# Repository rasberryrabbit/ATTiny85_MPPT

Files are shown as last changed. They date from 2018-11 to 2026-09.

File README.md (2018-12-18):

# ATTiny85
Solar MPPT circuit.
Fianally working first firmware, but it need more testing.
Button is calibrate op-amp offset voltage at no load. It stored EEPROM.

Coding by Arduino 1.8.7 / ATTinycore.
~Algorithm convert from old MPPT code of mine.~
It implement new simple algorithm that work well with high solar output.
~But it have low power output under low solar output condition(stuck in high voltage).~
It has no PWM noise at high load.(hopely)
It has 8KHz switching frequency.
It works better than old 16f676 or 12f675 version due to no PWM noise.

11 milli-ohm N-ch logic level FET(BUK9511) used for current sensor. 
It can replace by 11 mili-ohm or higher Rds-on(<40 milli) resistance logic level FET.

BUK9511-55A -> BUK9508-55A
Transistor 2N2222A -> BC547 or compatible
Transistor 2N2907A -> BC557 or compatible

L1 100~330uH

LM358N can replace by other pin-compatible regular OP-AMP.

D8-D9 used for 3.6v Reference. Each has about 1.8v voltage drop.

Q1 gate voltage is 3.6v. It's depend on FET specification.

Q1, Q2 can skip heat spreader with low POWER Solar panel. No heat with 10W panel.

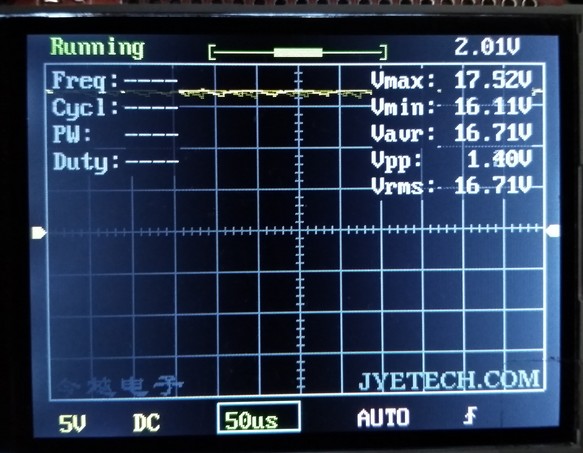
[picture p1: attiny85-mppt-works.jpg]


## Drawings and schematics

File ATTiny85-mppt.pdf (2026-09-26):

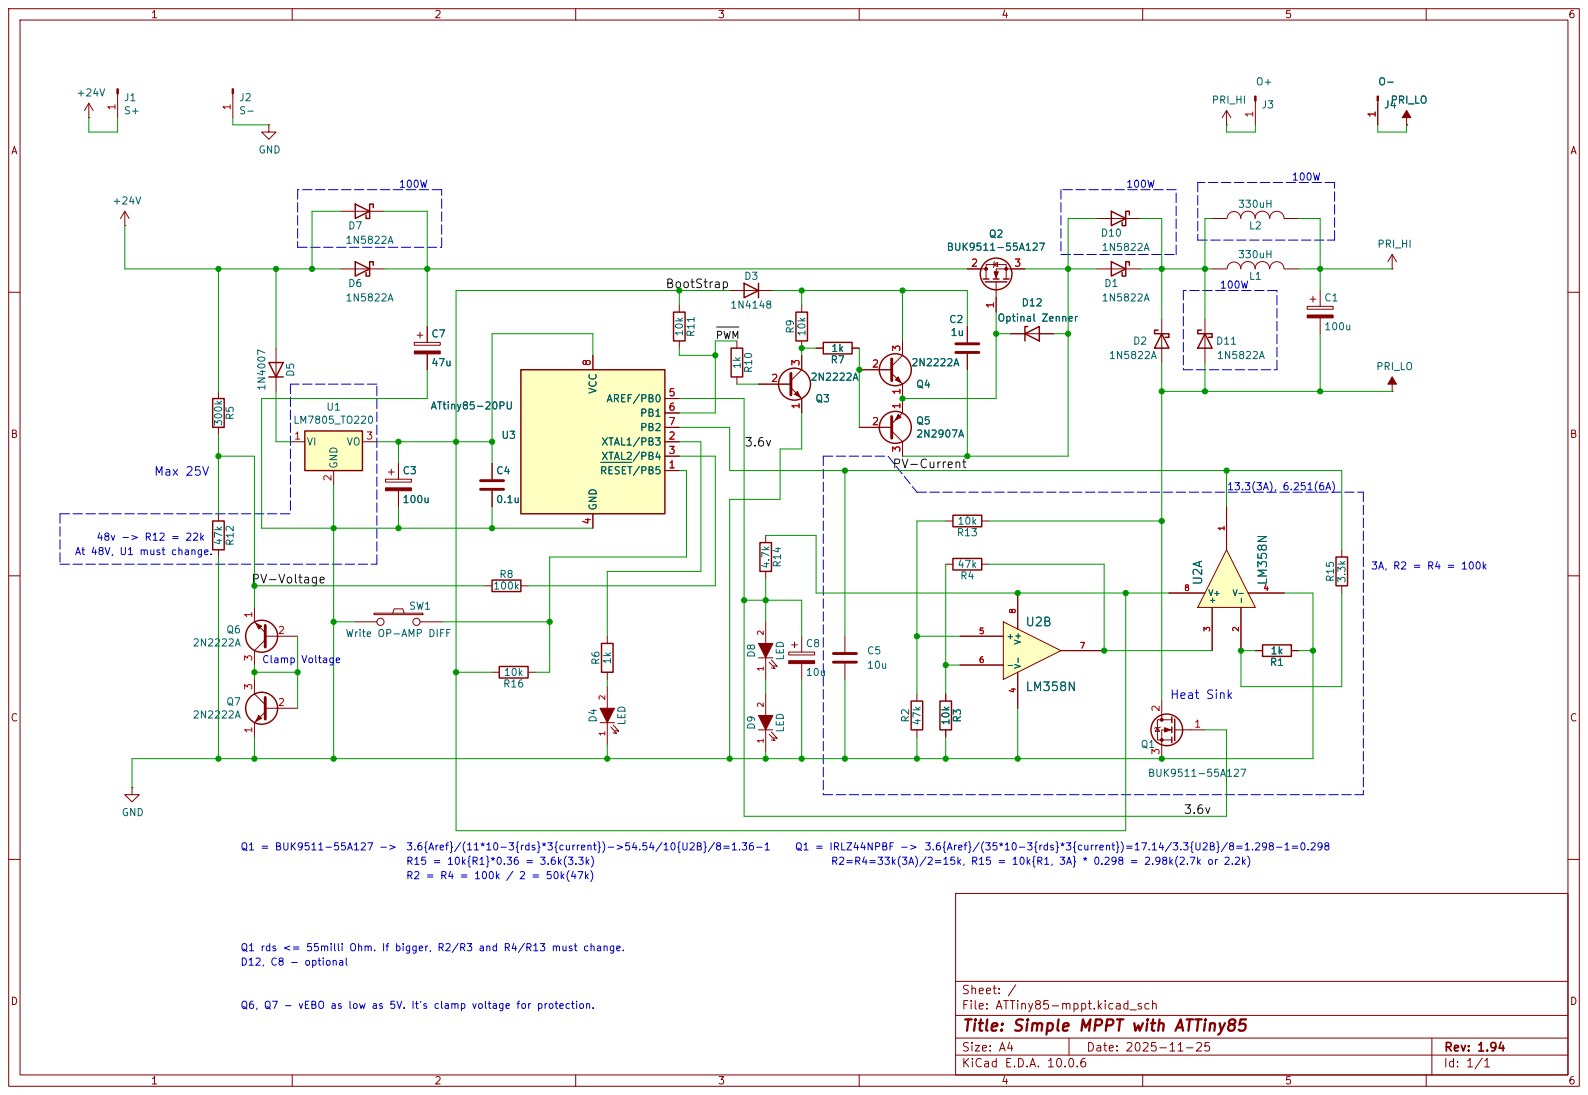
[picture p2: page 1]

Q1 rds <= 55milli Ohm. If bigger, R2/R3 and R4/R13 must change. R2 = R4 = 100k / 2 = 50k(47k)

Sheet: /
File: ATTiny85-mppt.kicad_sch
Title: Simple MPPT with ATTiny85

Q6, Q7 - vEBO as low as 5V. It's clamp voltage for protection.

Size: A4 | Rev: 1.94
KiCad E.D.A. 10.0.6 | Id: 1/1

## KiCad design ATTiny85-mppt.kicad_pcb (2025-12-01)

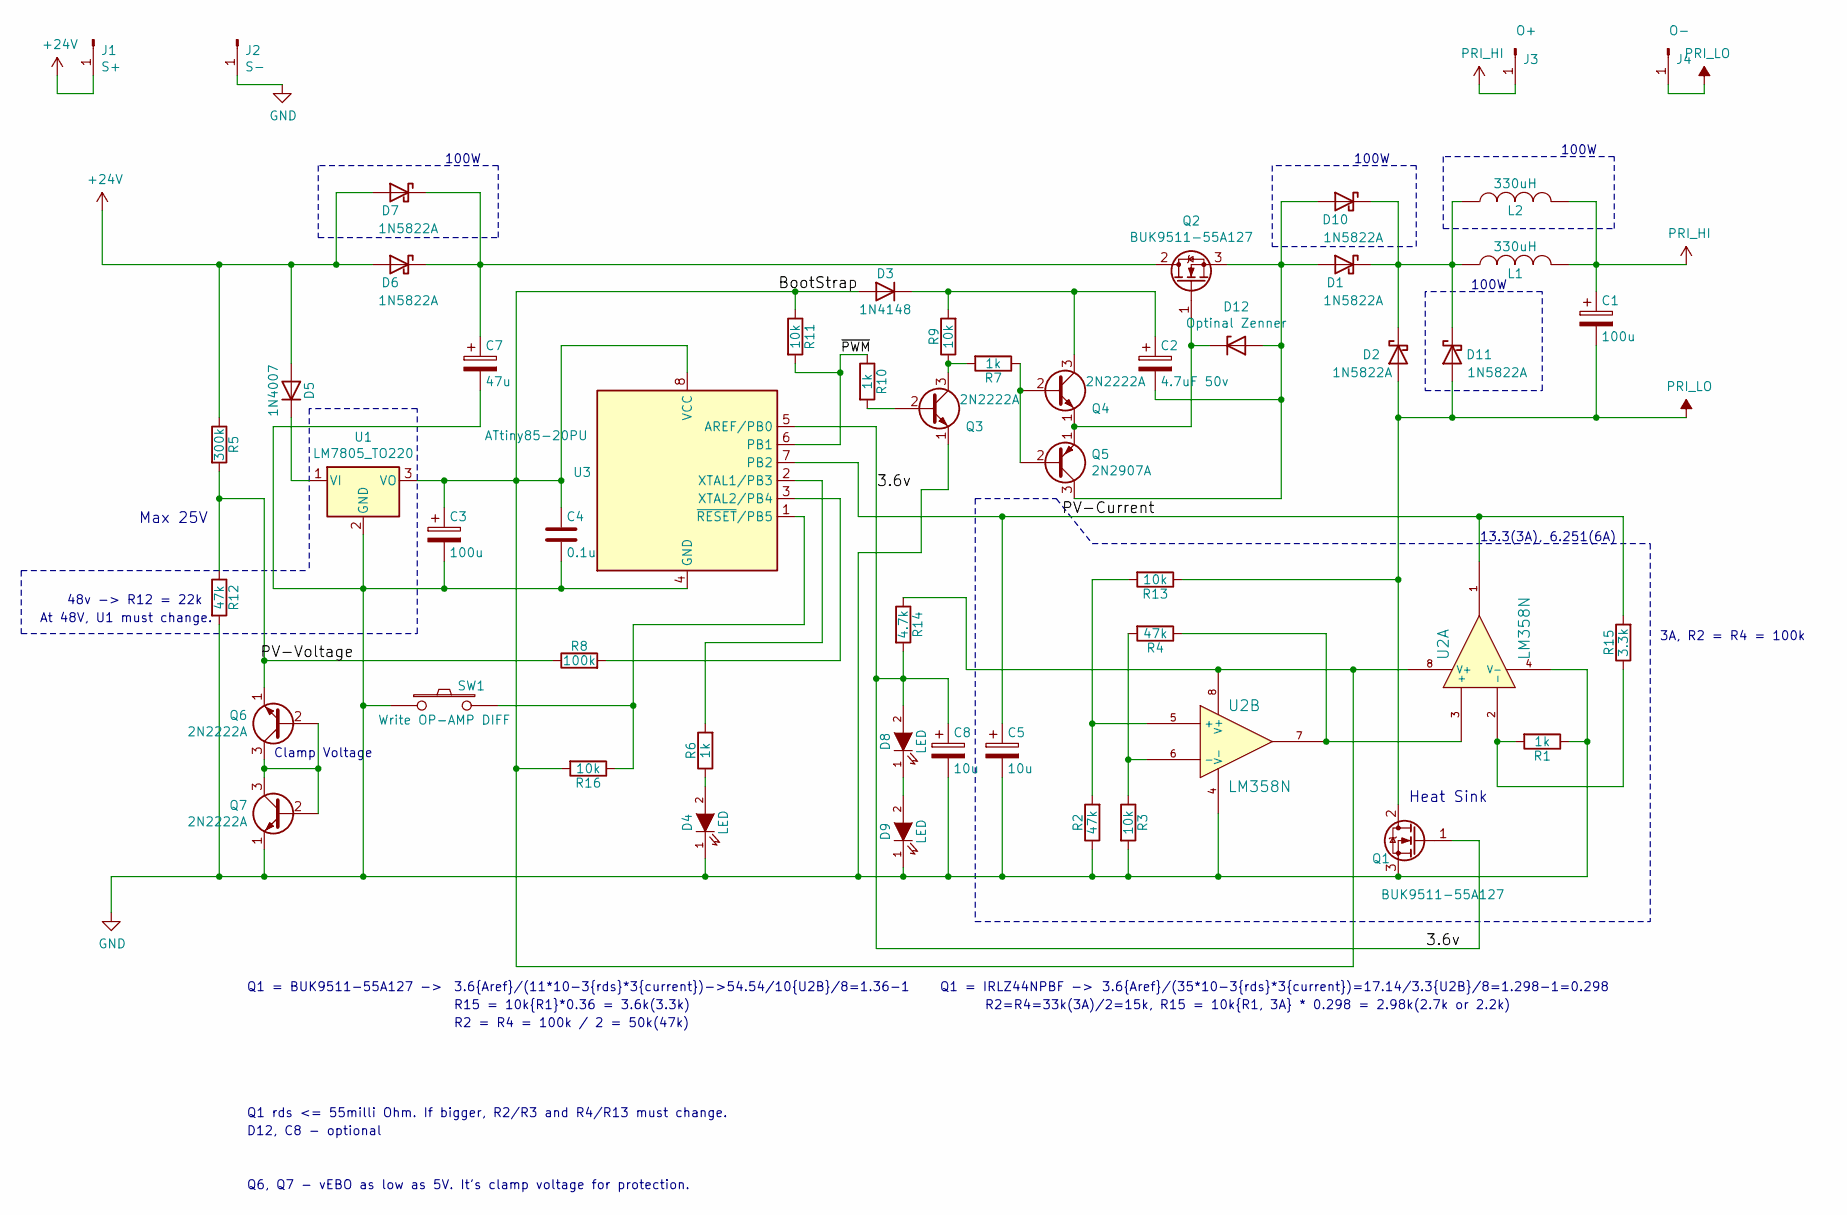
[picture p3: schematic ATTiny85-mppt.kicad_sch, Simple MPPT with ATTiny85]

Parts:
C1, C3: 100u; CP_Radial_D12.5mm_P5.00mm
C2: 4.7uF 50v; CP_Radial_D12.5mm_P5.00mm
C4: 0.1u; C_Disc_D12.5mm_W5.0mm_P7.50mm
C5, C8: 10u; CP_Radial_D12.5mm_P5.00mm
C7: 47u; CP_Radial_D12.5mm_P5.00mm
D1, D2, D6, D7, D10, D11: 1N5822A; D_DO-201AD_P15.24mm_Horizontal
D3: 1N4148; D_DO-41_SOD81_P10.16mm_Horizontal
D4, D8, D9: LED; LED_D4.0mm
D5: 1N4007; D_DO-41_SOD81_P10.16mm_Horizontal
D12: Optinal Zenner; D_DO-41_SOD81_P10.16mm_Horizontal
J1: S+; 1pin
J2: S-; 1pin
J3: O+; 1pin
J4: O-; 1pin
L1, L2: 330uH; L_Toroid_Vertical_L33.0mm_W17.8mm_P12.70mm_Pulse_KM-5
Q1, Q2: BUK9511-55A127; TO-220_Neutral123_Vertical
Q3, Q4, Q6, Q7: 2N2222A; TO-92_Inline_Wide
Q5: 2N2907A; TO-92_Inline_Wide
R1, R6, R7, R10: 1k; R_Axial_DIN0309_L9.0mm_D3.2mm_P12.70mm_Horizontal
R2, R4, R12: 47k; R_Axial_DIN0309_L9.0mm_D3.2mm_P12.70mm_Horizontal
R3, R9, R11, R13, R16: 10k; R_Axial_DIN0309_L9.0mm_D3.2mm_P12.70mm_Horizontal
R5: 300k; R_Axial_DIN0309_L9.0mm_D3.2mm_P12.70mm_Horizontal
R8: 100k; R_Axial_DIN0309_L9.0mm_D3.2mm_P12.70mm_Horizontal
R14: 4.7k; R_Axial_DIN0309_L9.0mm_D3.2mm_P12.70mm_Horizontal
R15: 3.3k; R_Axial_DIN0309_L9.0mm_D3.2mm_P12.70mm_Horizontal
SW1: Write OP-AMP DIFF; SW_PUSH_6mm
U1: LM7805_TO220; TO-220-3_Vertical
U2: LM358N; DIP-8_W7.62mm
U3: ATtiny85-20PU; DIP-8_W7.62mm

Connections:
+24V: D5.2 (A), D6.2 (A), D7.2 (A), J1.1, R5.1; also elsewhere on the board
/3.6v: C8.1, D8.2 (A), Q1.1 (G), R14.2, U3.5 (AREF/PB0)
/BootStrap: C3.1, C4.1, D3.2 (A), R11.1, R14.1, R16.2, U1.3 (VO), U2.8 (V+), U3.8 (VCC)
/PV-Current: C5.1, R15.2, U2.1, U3.7 (PB2)
/PV-Voltage: Q6.1 (E), R5.2, R8.1, R12.1
/~PWM: R10.1, R11.2, U3.6 (PB1)
GND: C3.2, C4.2, C5.2, C7.2, C8.2, D4.1 (K), D9.1 (K), J2.1, Q1.3 (S), Q3.1 (E), Q7.1 (E), R1.1, R2.1, R3.2, R12.2, SW1.1, U1.2 (GND), U2.4 (V-), U3.4 (GND); also elsewhere on the board
unnamed: C2.1, D3.1 (K), Q4.3 (C), R9.2
unnamed: C2.2, D1.2 (A), D10.2 (A), D12.2 (A), Q2.3 (S), Q5.3 (C)
unnamed: C7.1, D6.1 (K), D7.1 (K), Q2.2 (D)
unnamed: D1.1 (K), D2.1 (K), D10.1 (K), D11.1 (K), L1.1, L2.1
unnamed: D4.2 (A), R6.1
unnamed: D5.1 (K), U1.1 (VI)
unnamed: D8.1 (K), D9.2 (A)
unnamed: D12.1 (K), Q2.1 (G), Q4.1 (E), Q5.1 (E)
unnamed: Q3.2 (B), R10.2
unnamed: Q3.3 (C), R7.2, R9.1
unnamed: Q4.2 (B), Q5.2 (B), R7.1
unnamed: Q6.2 (B), Q6.3 (C), Q7.2 (B), Q7.3 (C)
unnamed: R1.2, R15.1, U2.2 (-)
unnamed: R3.1, R4.2, U2.6 (-)
unnamed: R4.1, U2.3 (+), U2.7
unnamed: R6.2, U3.2 (XTAL1/PB3)
unnamed: R8.2, U3.3 (XTAL2/PB4)
unnamed: R2.2, R13.2, U2.5 (+)
unnamed 25: R16.1, SW1.2, U3.1 (~RESET/PB5); also elsewhere on the board
PRI_HI: C1.1, J3.1, L1.2, L2.2; also elsewhere on the board
PRI_LO: C1.2, D2.2 (A), D11.2 (A), J4.1, Q1.2 (D), R13.1; also elsewhere on the board

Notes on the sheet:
3A, R2 = R4 = 100k
48v -> R12 = 22k
100W
3.6{Aref}/(11*10-3{rds}*3{current})->54.54/10{U2B}/8=1.36-1
Clamp Voltage
R2 = R4 = 100k / 2 = 50k(47k)
Heat Sink
D12, C8 - optional
Max 25V
At 48V, U1 must change.
13.3(3A), 6.251(6A)
Q1 = BUK9511-55A127 ->
Q1 rds <= 55milli Ohm. If bigger, R2/R3 and R4/R13 must change.
Q6, Q7 - vEBO as low as 5V. It's clamp voltage for protection.
R2=R4=33k(3A)/2=15k, R15 = 10k{R1, 3A} * 0.298 = 2.98k(2.7k or 2.2k)
Q1 = IRLZ44NPBF ->
R15 = 10k{R1}*0.36 = 3.6k(3.3k)
3.6{Aref}/(35*10-3{rds}*3{current})=17.14/3.3{U2B}/8=1.298-1=0.298

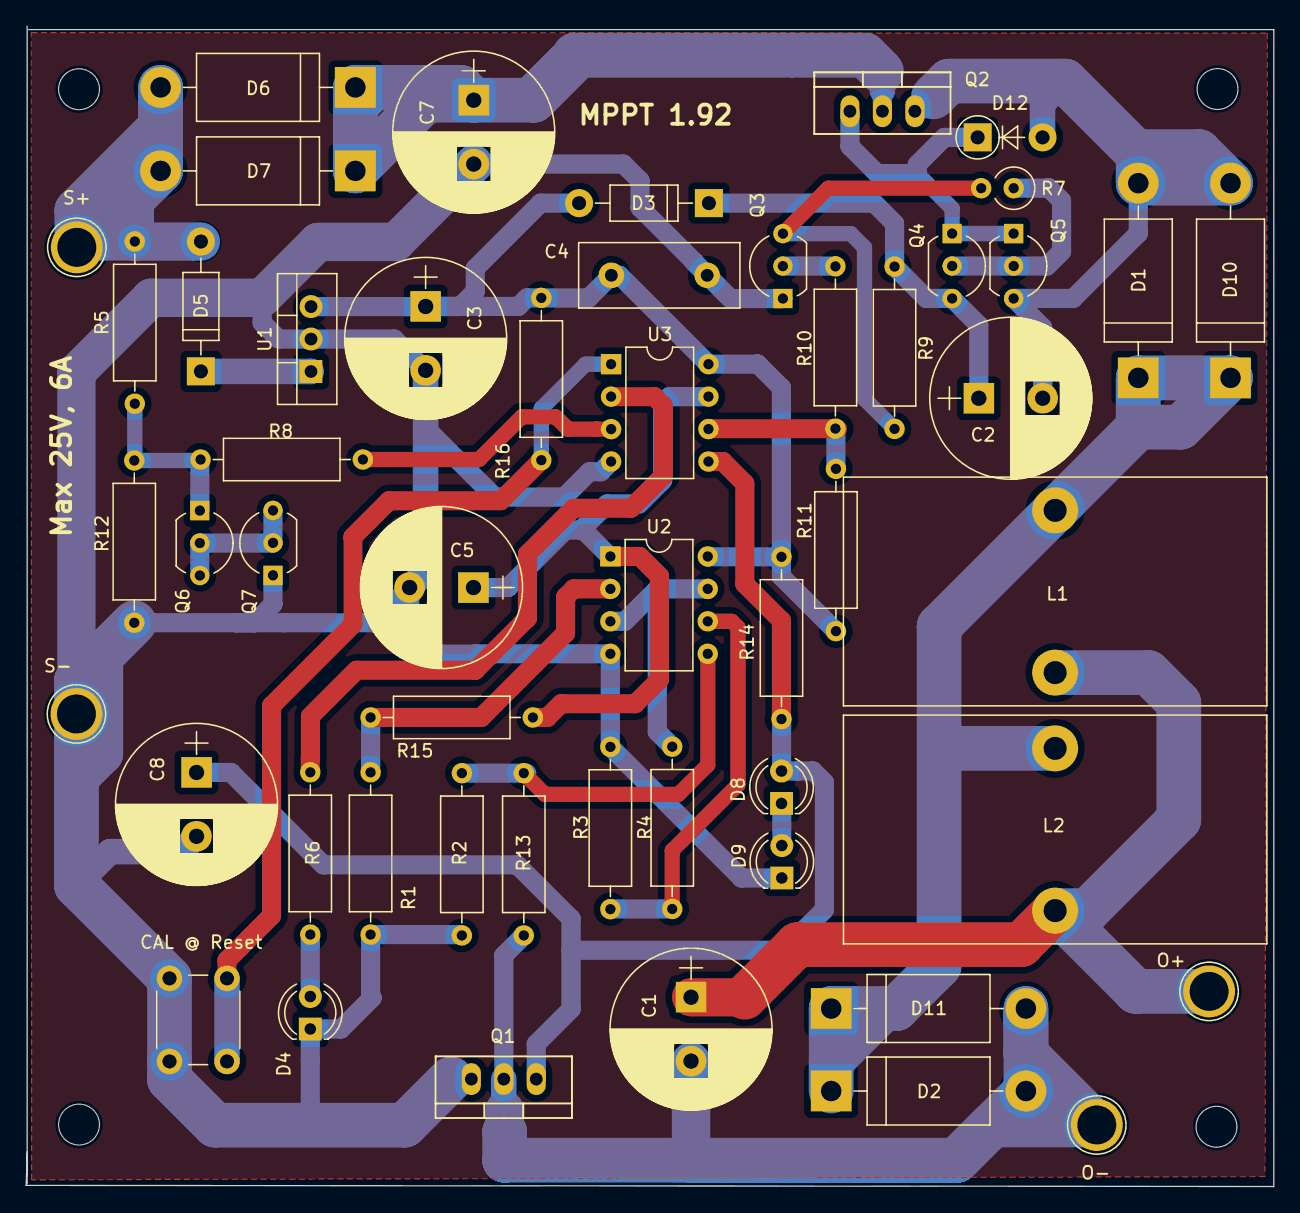
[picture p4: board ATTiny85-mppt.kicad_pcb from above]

Board: 2 copper layers, 97.6 x 90.8 mm, 52 parts (0 on the bottom side), 28 nets.

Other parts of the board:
CAL @ Reset: Write OP-AMP DIFF; SW_PUSH_6mm
O+: O+; 1pin
O-: O-; 1pin
S+: S+; 1pin
S-: S-; 1pin

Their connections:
+24V: S+.1; also elsewhere on the board
GND: CAL @ Reset.1, S-.1; also elsewhere on the board
unnamed 25: CAL @ Reset.2; also elsewhere on the board
PRI_HI: O+.1; also elsewhere on the board
PRI_LO: O-.1; also elsewhere on the board

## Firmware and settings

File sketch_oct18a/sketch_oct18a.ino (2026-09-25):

/*
  simple MPPT with ATTiny85 by rasberryrabbit @ github
  
  It need ATTinycore. https://github.com/SpenceKonde/ATTinyCore

  [Tool Option]
  BOD Enabled 4.3V,
  ATTiny85 (No Bootloader),
  Clock = 1MHz(internal),
  EEPROM retained, 
  LTO disabled,
  millis()/micros() enabled
  Timer1 clock = 32MHz

  High Fuse = DC (BOD 4.3V)
 */

#include <ATTinyCore.h>
#include <EEPROM.h>
#include <avr/wdt.h>

/* re-define Reference for ATTiny x5, bug fix */
// X 0 0 VCC used as Voltage Reference, disconnected from PB0 (AREF).
#define DEFAULT (B0000)
// X 0 1 External Voltage Reference at PB0 (AREF) pin, Internal Voltage Reference turned off.
#define EXTERNAL (B0100)
// 0 1 0 Internal 1.1V Voltage Reference.
#define INTERNAL (B1000)
#define INTERNAL1V1 INTERNAL
// 1 1 1 Internal 2.56V Voltage Reference with external bypass capacitor at PB0 (AREF) pin(1).
#define INTERNAL2V56 (B1101)
// 1 1 0 Internal 2.56V Voltage Reference without external bypass capacitor, disconnected from PB0 (AREF)(1).
#define INTERNAL2V56_NO_CAP (B1001)
#define INTERNAL2V56NOBP INTERNAL2V56_NO_CAP

// constants
#define PWM_MAX 200
#define PWM_START ((int)PWM_MAX * 10 / 100)
#define PWM_MIN ((int)PWM_MAX * 6 / 100)
#define PWM_END ((int)PWM_MAX * 45 / 100)
#define PWM_MID PWM_MAX/2-5
#define PWM_CHECK PWM_MID
#define CLM358_DIFF 0
#define INC_PWM_MAX 1
#define ADC_MAX_LOOP 4
#define INC_PWM_MIN 0
#define _UPDATE_INT 100
#define _UPDATE_VOL 1
#define _DEAD_BAND_LIMIT 50
#define NOISE_MARGIN 2

//#define USE_48V
#ifdef USE_48V
#define VINPUT 48
#else
#define VINPUT 25
#endif

//#define ADC_LOOP
//#define USE_CAL_ADC

#define VOLMUL ((int)VINPUT/6)  // Voltage vs Current = 25V(1024) / 6A(1024)

int LED1_tm;
int adc_cur, adc_vol, raw_vol;
long power_prev, power_curr, dead_band;
byte i, LM358_diff, streg;
boolean flag_inc, p_equal, wdtreset;
byte inc_pwm, pwm_power;
long prevtime, currtime, udtime, powertime, update_int;
byte doADCRead;
boolean startup_mode;
long startup_timer;

const char wdtdetect[] = "wdtreset";
char *p = (char *) malloc(sizeof(wdtdetect));

bool CheckWDT() {
  return(strcmp(p, wdtdetect) == 0);
}

// pin 
#define AREF PIN_B0
#define PWM PIN_B1
#define ADC_CUR_PIN PIN_B2
#define ADC_VOL_PIN PIN_B4
#define LED PIN_B3
#define ADC_CUR A1
#define ADC_VOL A2

void setup() {
  wdtreset = CheckWDT();
  p[0]=0;
  cli();
  MCUSR &= ~(1<<WDRF);
  WDTCR = (1<<WDE) | (1<<WDCE);
  WDTCR = (1<<WDE) | (1<<WDIE) | (1<<WDP3);    // 4 seconds watchdog
  sei();

  // ADC current
  pinMode(ADC_CUR_PIN, INPUT);
  // ADC Voltage
  pinMode(ADC_VOL_PIN, INPUT);
  pinMode(AREF, INPUT);
  analogReference(EXTERNAL);
  analogRead(ADC_CUR);  // prevent short

  pinMode(PWM, OUTPUT);
  OCR1A = 0;
  OCR1C = PWM_MAX - 1;
  TCCR1 = (1<<PWM1A)   |  // Enable PWM
          (1<<CS12)    |  // PCK/16, 2000000 / (199+1) = 10kHz
          (1<<CS10)    |
          (1<<COM1A0)  |
          (1<<COM1A1);    // inverting mode
  //GTCCR = (1 << PWM1B);
  
  // LED
  pinMode(LED, OUTPUT);

  // init
  LED1_tm = 500;

  LM358_diff = CLM358_DIFF;
  wdt_reset();

// calibration @ reset
#ifdef USE_CAL_ADC
  if((MCUSR & (1<<EXTRF)) && (!wdtreset)) {
    delay(500);    
    adc_cur = analogRead(ADC_CUR);
    EEPROM.write(0,lowByte(adc_cur));
    // EEPROM Write
    delay(100);
    digitalWrite(LED,1);
    delay(700);
    digitalWrite(LED,0);
    wdt_reset();
  }
#endif
  delay(100);
  LM358_diff = EEPROM.read(0);
  if(LM358_diff>0x3f)
    LM358_diff=0;

  delay(500);

  adc_vol = 0;
  adc_cur = 0;
  power_curr = 0;
  inc_pwm = 1;
  update_int = _UPDATE_INT;
    
  prevtime = millis();
  powertime = prevtime;
  udtime = prevtime;
  startup_mode = false;
  

  flag_inc = true;
  OCR1A = PWM_START;
  delay(300);
}

void debug_led() {
  digitalWrite(LED,1);
  delay(100);
  digitalWrite(LED,0);
}

long tick_diff(long a, long b) {
  if(a>=b)
    return a-b;
  else
    return b-a+1;
}

void loop() {
  // LED
  currtime = millis();
  if(tick_diff(currtime, prevtime) >= LED1_tm) {
    prevtime = currtime;
    boolean lv=digitalRead(LED);
    if(lv)
      digitalWrite(LED,LOW);
      else
        digitalWrite(LED,HIGH);
  }
  // get voltage, current
  // wait timer1 overflow
  while(bitRead(TIFR,TOV1)==0) ;
#ifndef ADC_LOOP
  delayMicroseconds(80);         // 10kHz, 100us, 100-20=80
#endif
  // get voltage, current
  adc_cur = analogRead(ADC_CUR);
  raw_vol = analogRead(ADC_VOL);
#ifdef ADC_LOOP
int temp1, temp2;
  for(i=0;i<ADC_MAX_LOOP-1;i++) {
    // read adc value
    temp2 = analogRead(ADC_CUR);
    temp1 = analogRead(ADC_VOL);
    adc_cur = (adc_cur+temp2) >> 1;
    raw_vol = (raw_vol+temp1) >> 1;
    //if(temp2 < adc_cur) {
    //  adc_cur = temp2;
    //  adc_vol = temp1;
    //}
  }
#endif
  adc_vol = raw_vol * VOLMUL;

  // long delay at low PWM
  currtime = millis();
  if(tick_diff(currtime, udtime) < update_int)
    goto CONTINUE;
  wdt_reset();
  udtime = currtime;
  // save previous adc values
  power_prev = power_curr;

  // get power
  power_curr = (long) adc_cur * adc_vol;

  dead_band = (long)(adc_cur + raw_vol) * VOLMUL * NOISE_MARGIN;
  if(dead_band < _DEAD_BAND_LIMIT)
    dead_band = _DEAD_BAND_LIMIT;
  // dead band limit 0.78% on high power
  if(power_curr > 10000) {
    if(dead_band > power_curr / 128)
      dead_band = power_curr / 128;
  }

  // active condition
  if(adc_cur > (LM358_diff+2)) {
    // startup delay
    if(startup_mode) {
      if(tick_diff(millis(), startup_timer)<3000) {
        LED1_tm=1000;
        flag_inc=raw_vol<400;
      } else
        startup_mode=false;
    }
    if(!startup_mode) {
      if(power_curr == power_prev) {
        LED1_tm = 500;
        goto CONTINUE;
      } else if(power_curr > power_prev) {
        if(power_curr-power_prev<dead_band) {
          LED1_tm = 500;
          goto CONTINUE;
        }
        LED1_tm = 300;
      } else {
        if(power_prev-power_curr<dead_band) {
          LED1_tm = 500;
          goto CONTINUE;
        }
        LED1_tm = 150;
        flag_inc = !flag_inc;
      }
    }
  } else {
    LED1_tm = 150;
    startup_mode=true;
    startup_timer=millis();
    // low current
    flag_inc = true;
    power_curr = 0;
    adc_cur = 0;
  }

CONT_PWM:

  if(flag_inc) {
    if(OCR1A < PWM_END)
      ++OCR1A;
      else {
        OCR1A = PWM_END;
        flag_inc = false;
      }
  } else {
    if(OCR1A > PWM_MIN)
      --OCR1A;
      else {
        OCR1A = PWM_MIN;
        flag_inc = true;
      }
  }

CONTINUE:
  ;
}

ISR(WDT_vect) {
  memcpy(p, wdtdetect, sizeof(wdtdetect));    // store watchdog signature
}

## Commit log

2018-10-24 fix pin mode on PWM.
    [sketch_oct18a.ino]
2018-10-24 Fix pin Names. Fix delay values for 1MHz clock. Diable OCAL(OP-AMP Calibration) to default.
    [sketch_oct18a.ino]
2018-10-25 Add hint for alternative FET IRLZ44.
    [ATTiny85-mppt.sch]
2018-10-25 Add formula for OP-AMP Current Detector Value.
    [ATTiny85-mppt.sch]
2018-10-26 Clarify alternative FET part number.
    [ATTiny85-mppt.sch]
2018-10-26 Update more reliable value for FET IRLZ44N.
    [ATTiny85-mppt.sch]
2018-10-28 fix OP-AMP formula.
    [ATTiny85-mppt.sch]
2018-10-28 Update comment for bigger rds FET.
    [ATTiny85-mppt.sch]
2018-10-30 Fix circuit - FET Bootstrap don't work. Fix code - Inverting mode PWM.
    [ATTiny85-mppt-B.Cu.gbr, ATTiny85-mppt-B.Mask.gbr, ATTiny85-mppt-B.SilkS.gbr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]
2018-10-30 Back to non-inverting. Fix FET Bootstrap.
    [ATTiny85-mppt-B.Cu.gbr, ATTiny85-mppt-B.Mask.gbr, ATTiny85-mppt-B.SilkS.gbr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]
2018-10-31 Fix by Invert Mode, 8Khz PWM. FET Bootstrap don't work with Higher frequency.
    [ATTiny85-mppt-B.Cu.gbr, ATTiny85-mppt-B.Mask.gbr, ATTiny85-mppt-B.SilkS.gbr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]
2018-10-31 Update PCB Layout.
    [ATTiny85-mppt-B.Cu.gbr, ATTiny85-mppt-B.Mask.gbr, ATTiny85-mppt-B.SilkS.gbr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]
2018-10-31 Down PWM clock to 4KHz. ADC check test
2018-11-01 Fix ADC reference parameter. Fix OP-AMP Offset at first.
    [sketch_oct18a.ino]
2018-11-01 fix FET bootstrap capacitor.
    [ATTiny85-mppt.sch]
2018-11-01 Lower Max PWM.
2018-11-02 Add another P FET for switching.
    [ATTiny85-mppt-B.Cu.gbr, ATTiny85-mppt-B.Mask.gbr, ATTiny85-mppt-B.SilkS.gbr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]
2018-11-02 add stall check. fix resetting parameters.
    [sketch_oct18a.ino]
2018-11-03 Fix low voltage condition
    [sketch_oct18a.ino]
2018-11-04 fix stall at low voltage.
    [sketch_oct18a.ino]
2018-11-10 Add AREF capacitor.
    [ATTiny85-mppt-B.Cu.gbr, ATTiny85-mppt-B.Mask.gbr, ATTiny85-mppt-B.SilkS.gbr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]
2018-11-13 remove some component.
    [ATTiny85-mppt-B.Cu.gbr, ATTiny85-mppt-B.Mask.gbr, ATTiny85-mppt-B.SilkS.gbr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]
2018-11-13 regenerate pcb files.
    [ATTiny85-mppt-B.Cu.gbr, ATTiny85-mppt-B.Mask.gbr, ATTiny85-mppt-B.SilkS.gbr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]
2018-11-15 Increase ADC checking loop count.
2018-11-15 update bootstrap capacitor.
    [ATTiny85-mppt.sch]
2018-11-17 update PCB file. update capacitor and add resistor.
    [ATTiny85-mppt.kicad_pcb, ATTiny85-mppt.sch]
2018-11-17 fix Q5 value.
    [ATTiny85-mppt.sch]
2018-11-17 change bootstrap diode.
    [ATTiny85-mppt.sch]
2018-11-18 clarify diode value.
    [ATTiny85-mppt.sch]
2018-11-18 refine pcb layout.
    [ATTiny85-mppt-B.Cu.gbr, ATTiny85-mppt-B.Mask.gbr, ATTiny85-mppt-B.SilkS.gbr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]
2018-11-18 rearrnage some lines.
    [ATTiny85-mppt.sch]
2018-11-18 rearrange lines.
    [ATTiny85-mppt-B.Cu.gbr, ATTiny85-mppt-B.Mask.gbr, ATTiny85-mppt-B.SilkS.gbr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]
2018-11-19 lower adc loop.
2018-11-19 back to old adc loop.
2018-11-19 Don't be over optimal power voltage.
2018-11-22 Change update interval under current condition.
2018-11-22 Change min max PWM and test.
2018-11-23 update interval on low current.
2018-11-24 stablize PWM.
2018-11-24 remove useless function and 8kHz PWM clock.
2018-11-25 add low current limit.
2018-11-25 check watchdog reset condition.
    [sketch_oct18a.ino]
2018-11-25 R11 to 4.7k
    [ATTiny85-mppt.sch]
2018-11-25 remove low current condition.
2018-11-26 avoid low voltage condition.
    [sketch_oct18a.ino]
2018-11-27 fix led delay.
2018-11-27 sync adc reading.
2018-11-27 use non-interrupt handler for sync
2018-11-28 improve adc routine
2018-11-28 reduce adc loop.
2018-11-29 Remove R11. It is a lot lower current sensing voltage.
    [ATTiny85-mppt.sch]
2018-11-29 Remove R11 on PCB layout.
    [ATTiny85-mppt-B.Cu.gbr, ATTiny85-mppt-B.Mask.gbr, ATTiny85-mppt-B.SilkS.gbr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]
2018-11-30 Test adc sample times.
2018-11-30 update PCB.
    [ATTiny85-mppt-B.Cu.gbr, ATTiny85-mppt-B.Mask.gbr, ATTiny85-mppt-B.SilkS.gbr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]
2018-11-30 update circuit.
    [ATTiny85-mppt.sch]
2018-12-07 update C2 value. 10uF is also good.
    [ATTiny85-mppt.sch]
2018-12-12 increase update interval. change ADC read order.
2018-12-13 fix current ADC reading. need more testing.
    [sketch_oct18a.ino]
2018-12-14 C6 to optional component.
    [ATTiny85-mppt.sch]
2018-12-14 typecast on power multiple calc.
2018-12-15 Low voltage-High current stuck solved by removing C6. More testing.
    [ATTiny85-mppt.sch]
2018-12-17 Remove C6
    [ATTiny85-mppt.sch]
2018-12-17 Describe arduino tool option.
2018-12-18 Add alternative FET.
2018-12-20 R15 -> 4.7k. Current sensing is more higher than expected. 62mA -> 67mV.
    [ATTiny85-mppt.sch]
2018-12-21 refine OP-AMP resistor formula. but it still same with first design(+10mV). it may safe under 3A current.
    [ATTiny85-mppt.sch]
2018-12-22 update resistor formula.
    [ATTiny85-mppt.sch]
2018-12-23 add note for R15.
    [ATTiny85-mppt.sch]
2018-12-26 Add voltage clamp.
    [ATTiny85-mppt.sch]
2019-01-07 fix low voltage(<2.7V) PLL lockup condition.
    [sketch_oct18a.ino]
2019-01-22 another fix for low vcc stall.
    [sketch_oct18a.ino]
2019-02-05 Back to old init order. BoD 2.7v is best for checking low voltage.
2019-02-06 make option PLL clock mode. Default to non-PLL clock for Timer1. It's unstable.
    [sketch_oct18a.ino]
2019-02-06 Update circuit. Limit load when control circuit voltage is low.
    [ATTiny85-mppt-B.Cu.gbr, ATTiny85-mppt-B.Mask.gbr, ATTiny85-mppt-B.SilkS.gbr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]
2019-02-08 Fix resistor values.
    [ATTiny85-mppt.sch]
2019-02-13 Back to old circuit. Fix power-up high-z on at FET.
    [ATTiny85-mppt.sch]
2019-02-15 Change low PWM values for boot strap charging.
2019-02-15 Fix R1, R15 values.
    [ATTiny85-mppt.sch]
2019-02-24 Update current sensing resistors.
    [ATTiny85-mppt.sch]
2019-03-23 Add 48V input option.
    [ATTiny85-mppt.sch]
2019-03-23 Add more comment.
    [ATTiny85-mppt.sch]
2019-05-05 Disable Overflow check on PWM.
2019-05-06 Enable overflow checking. It has more stable output voltage.
2019-06-09 Remove low voltage protection code.
2021-07-11 C2 -> 4.7uF
    [ATTiny85-mppt.sch]
2025-11-25 Fix circuit. R1 -> 1k.
    [ATTiny85-mppt.kicad_sch]
2025-11-27 Fix PWM.
2025-11-28 Add High Fuse Hint.
2025-12-01 Update PCB files.
    [ATTiny85-mppt.kicad_pcb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]
2025-12-01 Remove file.
    [ATTiny85-mppt-B_Mask.gbs]
2026-03-11 Check interval 18 to 19. Not much changes to output power. 18ms is most stable value.
2026-03-18 Revert checking interval to 18ms.
    [sketch_oct18a.ino]
2026-07-23 Try to fix low power condition when decreasing power.
    [sketch_oct18a.ino]
2026-07-31 Remove voltage multiplication operation.
2026-07-31 Change the current measurement method
2026-08-12 Restore voltage multiplier.
2026-08-13 Loosen power low checking.
    [sketch_oct18a.ino]
2026-08-13 Use ADC average values.
2026-09-07 Try to avoiding falling edge ringing.
    [sketch_oct18a.ino]
2026-09-11 Disable ADC calibration switch function and using as reset switch.
2026-09-22 Use dead band for more power output.
2026-09-23 Disable low current checking.
2026-09-24 Try to fix stalling.
    [sketch_oct18a.ino]
2026-09-25 To more reliably compare cumulative power changes, we adjust the update time and limit the maximum deadband at high powers to less than 1%.
2026-09-26 Update capacitors.
    [ATTiny85-mppt.kicad_sch]
